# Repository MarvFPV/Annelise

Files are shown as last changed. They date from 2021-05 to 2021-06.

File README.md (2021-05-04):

# Annelise
A PrimeE-Style gasket mounted 3d printable keyboard

!!Warning: Will not fit original PrimeE PCB!!

I have so far only printed one case, still waiting for plate. 
As this is basically an untested keyboard at this point, i have only released the f3z archive file for now. 
Feel free to tinker around, also, enable "component colour cycling", makes the timeline and whole project much nicer to work with.

More progess to this project will hopefully follow shortly. 

Pic of the case

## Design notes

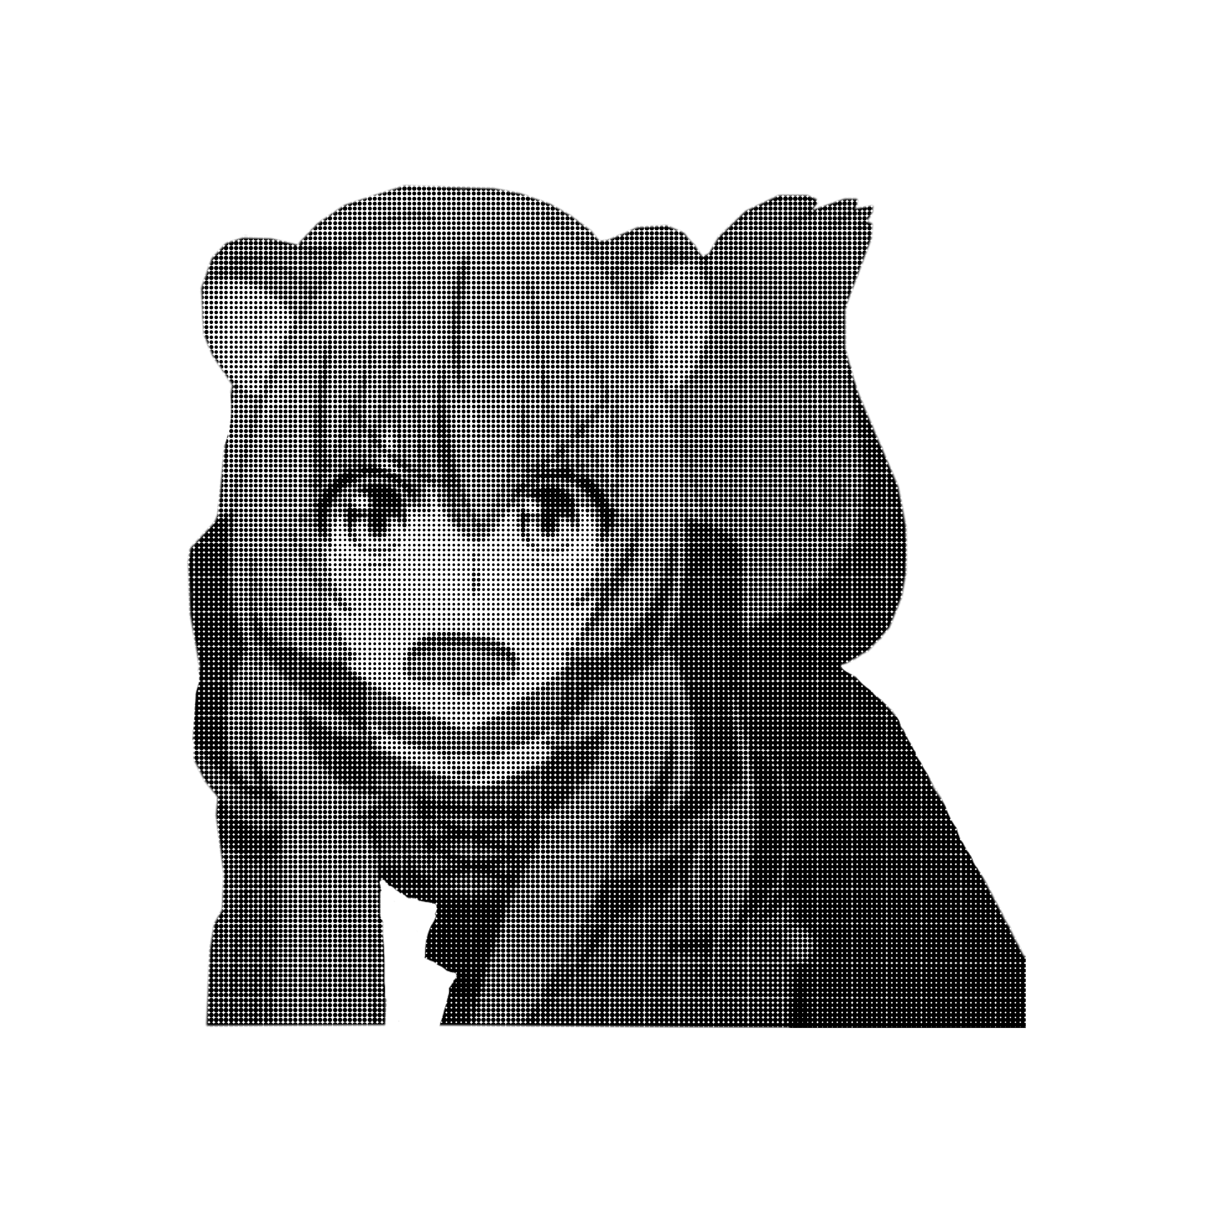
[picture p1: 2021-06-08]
PCB/raphtaliaboobs_gerbolyze.png

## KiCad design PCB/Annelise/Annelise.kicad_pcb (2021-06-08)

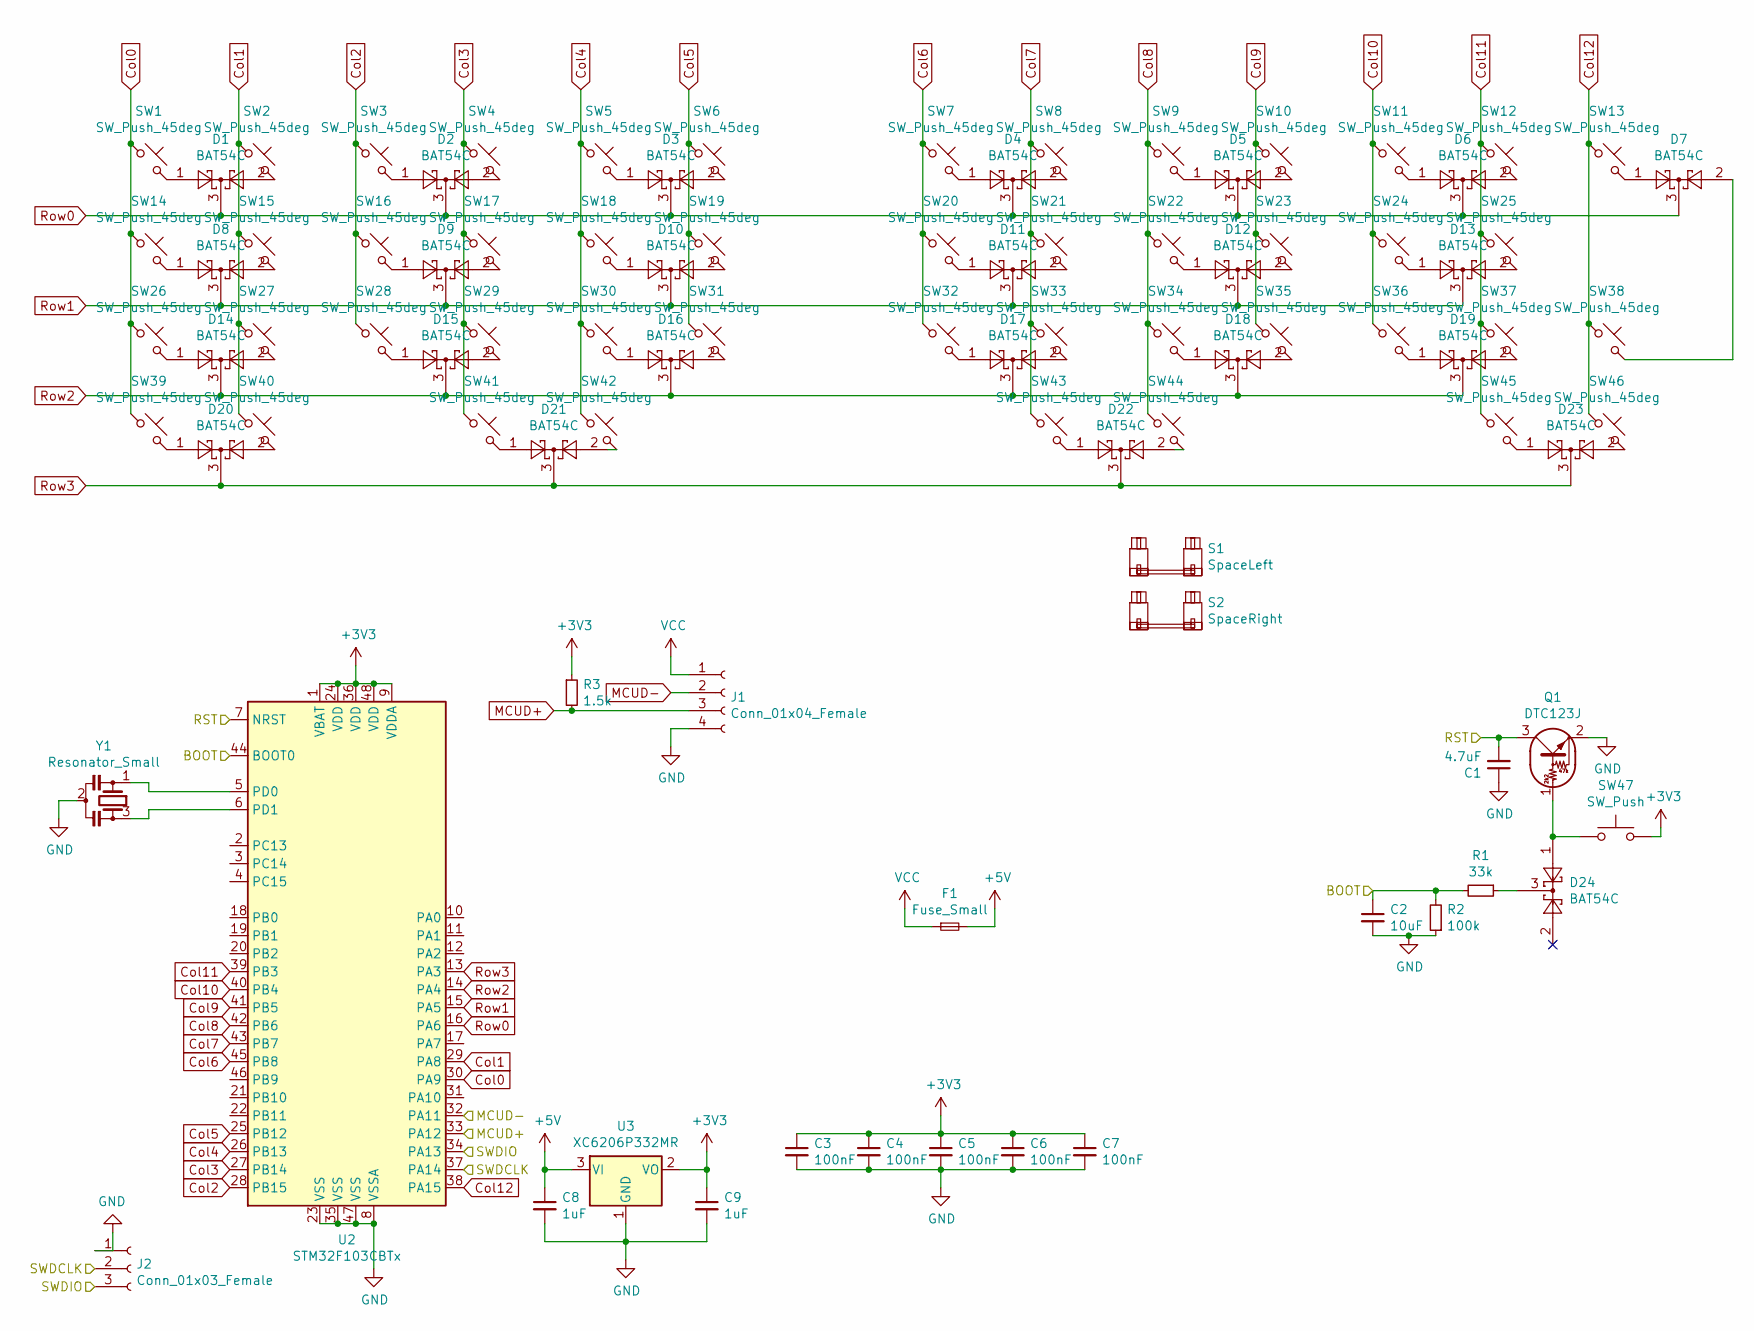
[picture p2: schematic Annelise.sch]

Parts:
C1: 4.7uF; C_0603_1608Metric
C2: 10uF; C_0603_1608Metric
C3, C4, C5, C6, C7: 100nF; C_0603_1608Metric
C8, C9: 1uF; C_0603_1608Metric
D1, D2, D3, D4, D5, D6, D7, D8, D9, D10, D11, D12, D13, D14, D15, D16, D17, D18, D19, D20, D21, D22, D23, D24: BAT54C; SOT-23
F1: Fuse_Small; Fuse_1206_3216Metric
J1: Conn_01x04_Female; JST_SH_SM04B-SRSS-TB_1x04-1MP_P1.00mm_Horizontal
J2: Conn_01x03_Female; PinHeader_1x03_P2.54mm_Vertical
Q1: DTC123J; SOT-23
R1: 33k; R_0603_1608Metric
R2: 100k; R_0603_1608Metric
R3: 1.5k; R_0603_1608Metric
S1: SpaceLeft; STAB_MX_2u
S2: SpaceRight; STAB_MX_2.25u
SW1, SW2, SW3, SW4, SW5, SW6, SW7, SW8, SW9, SW10, SW11, SW12, SW13, SW15, SW16, SW17, SW18, SW19, SW20, SW21, SW22, SW23, SW24, SW27, SW28, SW29, SW30, SW31, SW32, SW33, SW34, SW35, SW36, SW37, SW42, SW43: SW_Push_45deg; SW_MX_1u
SW14, SW38, SW39, SW40, SW41, SW44, SW45, SW46: SW_Push_45deg; SW_MX_1.25u
SW25, SW26: SW_Push_45deg; SW_MX_1.75u
SW47: SW_Push; PinHeader_1x02_P1.27mm_Vertical
U2: STM32F103CBTx; LQFP-48_7x7mm_P0.5mm
U3: XC6206P332MR; SOT-23
Y1: Resonator_Small; Resonator_SMD_muRata_CSTxExxV-3Pin_3.0x1.1mm

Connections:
+3V3: C3.1, C4.1, C5.1, C6.1, C7.1, C9.1, R3.1, SW47.2, U2.1 (VBAT), U2.9 (VDDA), U2.24 (VDD), U2.36 (VDD), U2.48 (VDD), U3.2 (VO); also elsewhere on the board
+5V: C8.1, F1.2, U3.3 (VI)
/BOOT: C2.1, R1.2, R2.2, U2.44 (BOOT0)
/RST: C1.2, Q1.3 (C), U2.7 (NRST)
/SWDCLK: J2.2, U2.37 (PA14); also elsewhere on the board
/SWDIO: J2.3, U2.34 (PA13); also elsewhere on the board
Col0: SW1.1, SW14.1, SW26.1, SW39.1, U2.30 (PA9)
Col1: SW2.1, SW15.1, SW27.1, SW40.1, U2.29 (PA8)
Col2: SW3.1, SW16.1, SW28.1, U2.28 (PB15)
Col3: SW4.1, SW17.1, SW29.1, SW41.1, U2.27 (PB14)
Col4: SW5.1, SW18.1, SW30.1, SW42.1, U2.26 (PB13)
Col5: SW6.1, SW19.1, SW31.1, U2.25 (PB12)
Col6: SW7.1, SW20.1, SW32.1, U2.45 (PB8)
Col7: SW8.1, SW21.1, SW33.1, SW43.1, U2.43 (PB7)
Col8: SW9.1, SW22.1, SW34.1, SW44.1, U2.42 (PB6)
Col9: SW10.1, SW23.1, SW35.1, U2.41 (PB5)
Col10: SW11.1, SW24.1, SW36.1, U2.40 (PB4)
Col11: SW12.1, SW25.1, SW37.1, SW45.1, U2.39 (PB3)
Col12: SW13.1, SW38.1, SW46.1, U2.38 (PA15)
GND: C1.1, C2.2, C3.2, C4.2, C5.2, C6.2, C7.2, C8.2, C9.2, J1.4, J2.1, Q1.2 (E), R2.1, U2.8 (VSSA), U2.23 (VSS), U2.35 (VSS), U2.47 (VSS), U3.1 (GND), Y1.2; also elsewhere on the board
MCUD+: J1.3, R3.2, U2.33 (PA12)
MCUD-: J1.2, U2.32 (PA11)
unnamed: D1.1, SW1.2
unnamed: D1.2, SW2.2
unnamed: D2.1, SW3.2
unnamed: D2.2, SW4.2
unnamed: D3.1, SW5.2
unnamed: D3.2, SW6.2
unnamed: D4.1, SW7.2
unnamed: D4.2, SW8.2
unnamed: D5.1, SW9.2
unnamed: D5.2, SW10.2
unnamed: D6.1, SW11.2
unnamed: D6.2, SW12.2
unnamed: D7.1, SW13.2
unnamed: D7.2, SW38.2
unnamed: D8.1, SW14.2
unnamed: D8.2, SW15.2
unnamed: D9.1, SW16.2
unnamed: D9.2, SW17.2
unnamed: D10.1, SW18.2
unnamed: D10.2, SW19.2
unnamed: D11.1, SW20.2
unnamed: D11.2, SW21.2
unnamed: D12.1, SW22.2
unnamed: D12.2, SW23.2
unnamed: D13.1, SW24.2
unnamed: D13.2, SW25.2
unnamed: D14.1, SW26.2
unnamed: D14.2, SW27.2
unnamed: D15.1, SW28.2
unnamed: D15.2, SW29.2
unnamed: D16.1, SW30.2
unnamed: D16.2, SW31.2
unnamed: D17.1, SW32.2
unnamed: D17.2, SW33.2
unnamed: D18.1, SW34.2
unnamed: D18.2, SW35.2
unnamed: D19.1, SW36.2
unnamed: D19.2, SW37.2
unnamed: D20.1, SW39.2
unnamed: D20.2, SW40.2
unnamed: D21.1, SW41.2
unnamed: D21.2, SW42.2
unnamed: D22.1, SW43.2
unnamed: D22.2, SW44.2
unnamed: D23.1, SW45.2
unnamed: D23.2, SW46.2
unnamed 68: D24.1, Q1.1 (B), SW47.1; also elsewhere on the board
unnamed: D24.3, R1.1
unnamed: U2.5 (PD0), Y1.1
unnamed: U2.6 (PD1), Y1.3
Row0: D1.3, D2.3, D3.3, D4.3, D5.3, D6.3, D7.3, U2.16 (PA6)
Row1: D8.3, D9.3, D10.3, D11.3, D12.3, D13.3, U2.15 (PA5)
Row2: D14.3, D15.3, D16.3, D17.3, D18.3, D19.3, U2.14 (PA4)
Row3: D20.3, D21.3, D22.3, D23.3, U2.13 (PA3)
VCC: F1.1, J1.1

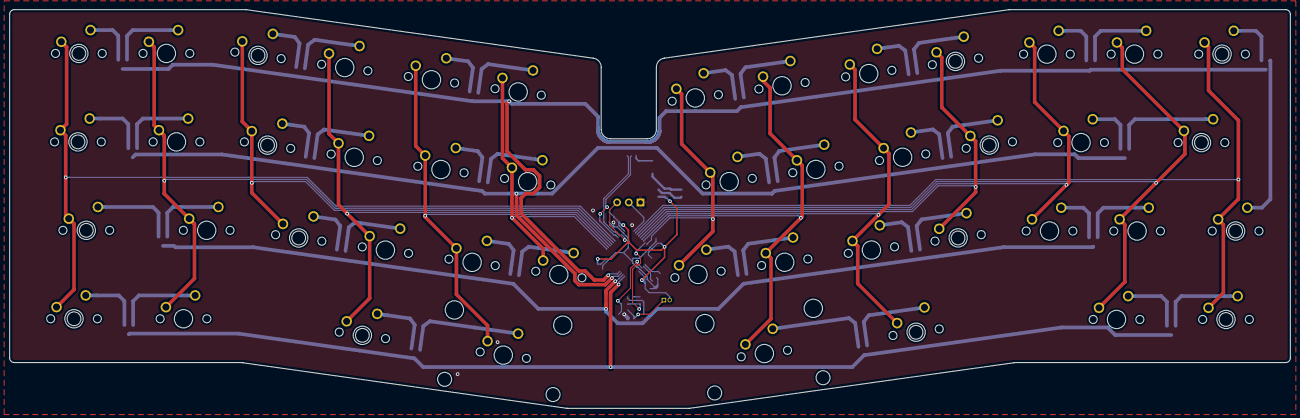
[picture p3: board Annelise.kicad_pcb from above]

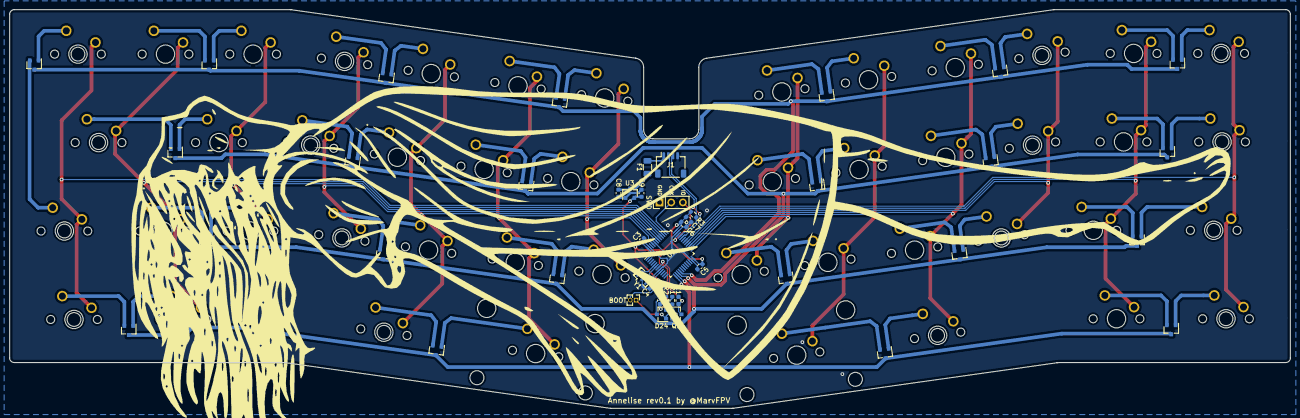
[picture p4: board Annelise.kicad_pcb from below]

Board: 2 copper layers, 278.6 x 86.7 mm, 92 parts (44 on the bottom side), 77 nets.

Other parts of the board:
BOOT: SW_Push; PinHeader_1x02_P1.27mm_Vertical
SWD: Conn_01x03_Female; PinHeader_1x03_P2.54mm_Vertical

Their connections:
+3V3: BOOT.2; also elsewhere on the board
/SWDCLK: SWD.2; also elsewhere on the board
/SWDIO: SWD.3; also elsewhere on the board
GND: SWD.1; also elsewhere on the board
unnamed 68: BOOT.1; also elsewhere on the board

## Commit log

2021-05-04 pcb started
    [Annelise.kicad_pcb, Annelise.sch]
2021-05-04 pcb updates
    [Annelise.kicad_pcb, Annelise.sch]
